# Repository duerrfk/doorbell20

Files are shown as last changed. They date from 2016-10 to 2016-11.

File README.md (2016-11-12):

# What is DoorBell20?

Door Bell 2.0 (or DoorBell20 for short) is a Bluetooth Low Energy (BLE) appliance to monitor a door bell and send notifications whenever the door bell rings. It turns a conventional door bell into a smart door bell that can be connected to the Internet of Things (IoT). Thus, DoorBell20 is the modern version of a door bell, or, as the name suggests, the door bell version 2.0 for the IoT era.

DoorBell20 consists for two major parts:

* The DoorBell20 monitoring device, which is connected in parallel to the door bell and wirelessly via BLE to a client running on a remote IoT gateway, e.g., a Raspberry Pi with Bluetooth stick.
* A DoorBell20 client running on the IoT gateway passing on notifications received via BLE to a remote cloud service. Different clients can be implemented for different IoT cloud services. So far, DoorBell20 includes a client for [If This Then That (IFTTT)](https://ifttt.com), which makes it very easy to trigger different actions when a door bell event is detected. For instance, a notification can be sent to a mobile phone or trigger an IP camera installed at the door to take pictures.

```
                  [IoT Cloud Service]
                  [  (e.g., IFTTT)  ]
                           | ^
                 Internet  | | Door Bell Event Notifications
                           |
                [      IoT Gateway      ]
                [ w/ DoorBell20 Client  ]
                [ (e.g., IFTTT Trigger) ]
                           |  ^
           BLE Connection  |  | Door Bell Event Notifications  
                           |
|-----------[DoorBell20 Monitoring Device]---------|
|                                                  |
|--------------------[Door Bell]-------------------|
|                                                  |
|                                                  |
|                                                 \   Door Bell Push Button
|                                                  \
|                                                  |
|----------------(Voltage Source)------------------|
                 (    12 VAC    )
```  

The following images show the DoorBell20 monitoring device, its connection to a door bell, and a door bell event notification displayed by the If This Then That (IFTTT) app on a mobile phone. 

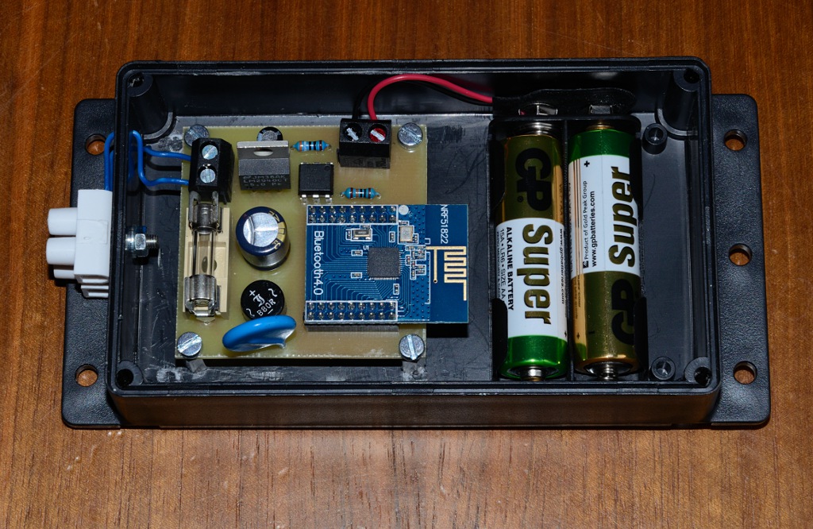
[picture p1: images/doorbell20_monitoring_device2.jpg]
DoorBell20 Monitoring Device

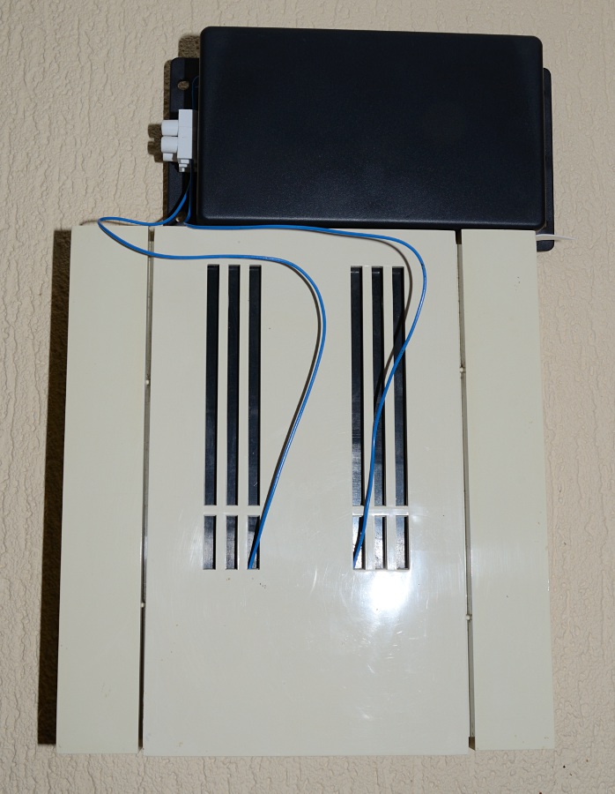
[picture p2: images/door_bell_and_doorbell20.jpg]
DoorBell20 Monitoring Device

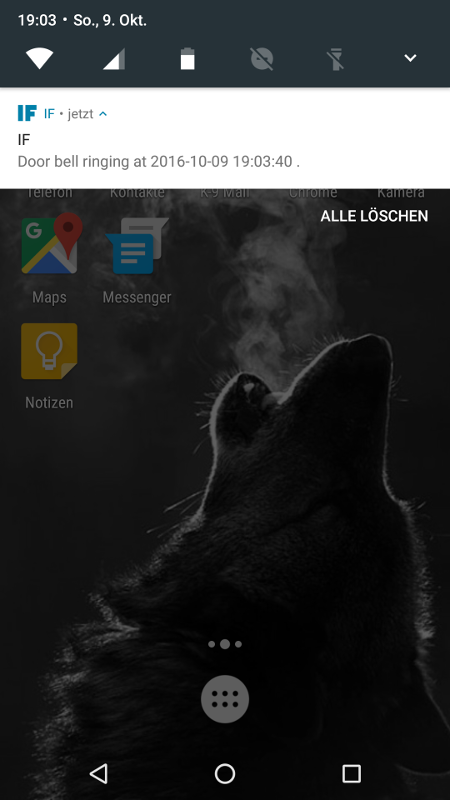
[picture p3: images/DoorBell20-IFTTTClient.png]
IFTTT Door Bell Notification


The main features of DoorBell20 are:

* Open-source software and hardware. Source code for the door bell monitoring device and IFTTT client as well as Eagle files (schematic and board layout) are provided.
* Maker-friendly: using easily available cheap standard components (nRF51822 BLE chip, standard electronic parts), easy to manufacture circuit board, and open-source software and hardware design.
* Includes a client for the popular and versatile If This Then That (IFTTT) service to facilitate the development of IoT applications integrating DoorBell20. 
* Liberal licensing of software and hardware under the Apache License 2.0 and the CERN Open Hardware License 1.0, respectively.

# DoorBell20 Monitoring Device

## Hardware

The following images show the DoorBell20 hardware and schematic.

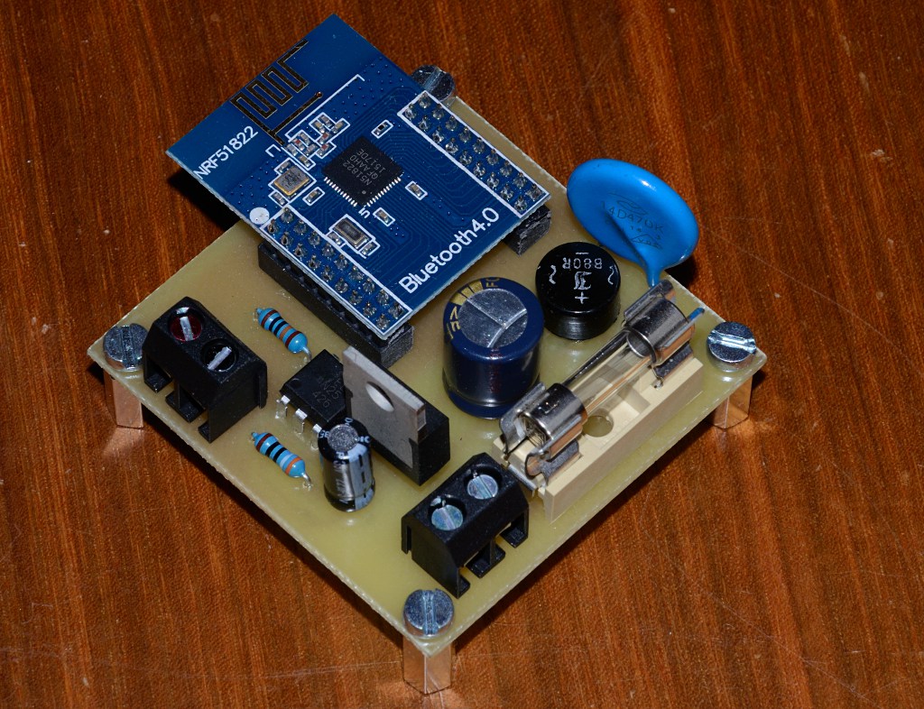
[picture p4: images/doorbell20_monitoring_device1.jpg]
DoorBell20 Monitoring Device

DoorBell20 Monitoring Device
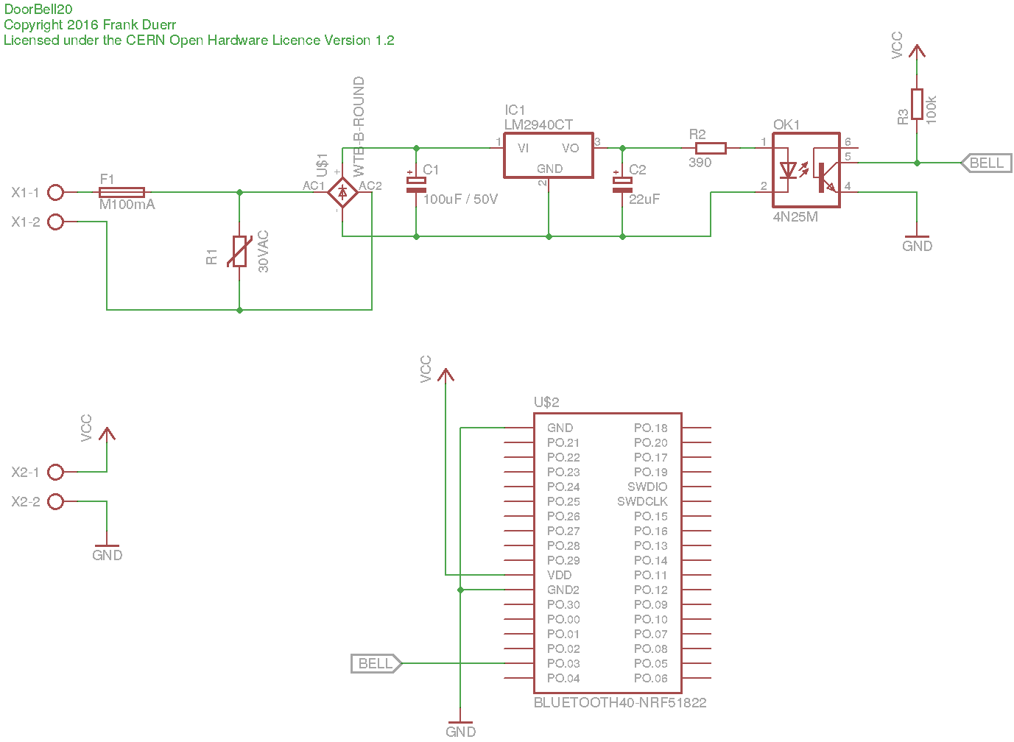
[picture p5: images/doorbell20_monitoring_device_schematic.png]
DoorBell20 Schematic


The DoorBell20 monitoring device is based on the BLE chip [nRF51822](https://www.nordicsemi.com/eng/Products/Bluetooth-low-energy/nRF51822) by Nordic Semiconductors. The nRF51822 features an ARM Cortex M0 processor implementing both, the application logic and the BLE stack (so-called softdevice). DoorBell20 uses the S110 softdevice version 8.0. See next sub-section on how to flash the softdevice and the application code. We use a so-called "Bluetooth 4.0" breakout boards with an nRF51822 (version 3, variant AA w/ 16 kB of RAM and 256 kB flash memory) and two 2x9 connectors (2 mm pitch), which you can buy over the Internet for about 6 US$ including shipping.

We isolate the 12 VAC door bell circuit from the microcontroller using an opto-isolator. A rectifier and 5 V voltage regulater is used to power the LED of the opto-isolator whenever the door bell is ringing. A GPIO pin of the nRF51822 connected to the other side of the opto-isolator is then detecting the event. In addition to the integrate protection mechanisms of the LM2940 voltage regulator (short circuit and thermal overload protection, shutdown during transients), a varistor protects from voltage transients since many door bells are inductive loads inducing voltage spikes when switched off. Since varistors age with every voltage transient, a fuse is added to protect the door bell circuit from a short circuit of the varistor.

The nRF51822 is powered by two AA batteries. No additional voltage regulator is required, which increased the energy efficiency, and the monitoring device is expected to run for years from a pair of AA batteries. Note that we did not implement a reverse polarity protection, so be careful to insert the batteries correctly.    

The circuit board layout (PCB) of the DoorBell20 monitoring device for Eagle can be found in folder ```pcb/doorbell20```. We deliberately used a simple single-sided through-hole design to help makers producing their own boards.

## Software/Firmware

The software for the DoorBell20 monitoring device can be found in directory ```nrf51/doorbell20```. 

### Prerequisites for Building the Software

No heavy-weight IDE is required to build the code. However, still a few tools are required to build and flash the code (tested with the given version numbers):

* [nRF51 SDK, version 10.0.0](http://developer.nordicsemi.com/nRF5_SDK/)
* [nRF5x Command Line Tools, version 8.2.0](https://www.nordicsemi.com/eng/Products/nRF51-DK)
* [Softdevice S110, version 8.0.0](https://www.nordicsemi.com/eng/Products/nRF51-DK)
* Flashing and debugging hardware, e.g., [Segger J-Link EDU](https://www.segger.com/j-link-edu.html) (about 50 US$, only for non-commerical use!). The nRF51 Developers Kit (DK) comes with an on-board Segger programmer, but for flashing the DoorBell20 board, you need an external programmer like the J-Link EDU. 
* [Tool chain (compiler, linker, etc.) for ARM](https://launchpad.net/gcc-arm-embedded/+download)

### Building and Flashing the Software

First, adapt the Makefile by defining the following variables:

* `NRF51_SDK`: path to the nRF51 SDK directory
* `CROSS`: path to the compiler tools
* `CFLAGS`: add `-DTARGET_BOARD_NRF51DK` if you compile for the nRF51 Development Kit (DK); if this definition is not set, you compile for the DoorBell20 board.
* `LINKER_SCRIPT`: set to `nrf51422_ac_s110.ld` for the nRF51 DK (nRF51422, variant AC) or to `nrf51822_aa_s110.ld` for the DoorBell20 board (nRF51822, variant AA).

Compiling the code:

```
$ cd nrf51
$ make
```

Flashing the softdevice:

```
$ nrfjprog --family NRF51 --program s110_nrf51_8.0.0_softdevice.hex --chiperase --verify
```

Flashing the application:

```
nrfjprog --family NRF51 --program doorbell20.hex --verify --sectorerase
```

Rebooting after flashing:

```
nrfjprog -r
```

# IFTTT DoorBell20 Client

DoorBell20 can be connected to any BLE client running on a remote machine. After receiveing a BLE notification about a door bell event, the client can then trigger local actions, and can forward the event to a remote IoT cloud service. DoorBell20 comes with a client for connecting to the popular [If This Then That (IFTTT)](https://ifttt.com/) cloud service.

You find the [nodejs](https://nodejs.org/) implementation of the IFTTT client in directory `client/ifttt`. With this client, you can use door bell alarm events as triggers for IFTTT. IFTTT offers you a broad choice of actions such as showing a notification on your smartphone when the bell rings, playing a sound on your phone, or sending a tweet to Twitter (if that makes sense to you). You could also trigger other IoT devices like an IP camera making a picture of the one standing at the door. 

The IFTTT DoorBell20 client subscribes for BLE notifications using the nodejs library [noble](https://github.com/sandeepmistry/noble). Whenever a notification for a door bell alarm is received, a web request is sent to the IFTTT maker channel triggering an event with a pre-defined name (we use the event name `door_bell_alarm` in our example). You can then define your own IFTTT recipes to decide what to do with this event like showing a notification on your smartphone through the IFTTT app. 

The following screenshot shows an IFTTT notification on an Android phone triggered by a door bell event that was delivered over the IFTTT Maker Channel.

IFTTT Door Bell Notification

## Prerequisites

The IFTTT client relies on the following software to be installed on the BLE client machine (your IoT gateway):

* nodejs (tested with nodejs version 4.6.0)
* noble
* C++ compiler with C++11 support for installing noble with npm as described below (tested with gcc/g++ 4.8.4). If you use Raspbian: gcc/g++ 4.8.4 included with Raspbian Jessie will work, but gcc/g++ 4.6.3 included with Raspbian Wheezy won't.  

Nodejs can be installed as root like this on a Raspberry Pi A/A+, B/B+, and Zero (ARMv6):

```
$ cd /usr/local
$ wget http://nodejs.org/dist/latest-v4.x/node-v4.6.0-linux-armv6l.tar.xz
$ tar axf node-v4.6.0-linux-armv6l.tar.xz
```

For other platforms, you have to replace `node-v4.6.0-linux-armv6l.tar.xz` by the corresponding file, e.g., `node-v4.6.0-linux-armv7l.tar.xz` for Raspberry Pi 2 (ARMv7) or `node-v4.6.0-linux-x64.tar.xz` for 64 bit Linux.

Make sure to add the nodejs `bin` directory to your path, so the commands `node`and `npm` can be found.

With nodejs installed, install the noble library for implementing BLE centrals:

```
$ sudo apt-get install bluetooth bluez libbluetooth-dev libudev-dev
$ cd doorbell20/client/ifttt
$ npm install noble
```

This should create the sub-directory `node_modules` in directory `doorbell20/client/ifttt`.

The first line installs Bluetooth libraries required by noble on Debian-based systems including Ubuntu and Raspbian. You might need to modify this depending on your platform, e.g., for Fedora:

```
$ sudo yum install bluez bluez-libs bluez-libs-devel
```

Please consult the [noble page](https://github.com/sandeepmistry/noble) for other platforms.

## Executing the IFTTT Client

The client can be started like this:

```
sudo node doorbell20-client-ifttt.js 'ABCDEFGHIJK1234567890' 'f3:23:0d:4c:ce:1b' 'doorbell_alarm' 'iot_failure'
```

Argument `ABCDEFGHIJK1234567890` is the key of your IFTTT Maker channel (obviously here a bogus one), which you get when you register with the Maker channel through the IFTTT web interface or app.

Argument `doorbell_alarm` is the name of the generated events. You can send many different events to your Maker channel, e.g., from your door bell, from your smoke detector (hopefully not so often), etc. The event name defines, which event has been fired.

A second event called `iot_failure` is defined that will be triggerer when the client could not connect to the DoorBell20 monitoring device over BLE to signal a permanent failure, e.g., when the battery of the monitoring device is empty. 

Argument `f3:23:0d:4c:ce:1b` is the MAC address of your DoorBell20 BLE device. You might have installed different DoorBell20 devices for different door bells, so the DoorBell20 service UUID is not enough to distinguish between different devices. The MAC address is unique for each device.

## Source Code

The source code of the IFTTT client can be found in file `doorbell20-client-ifttt.js`. It should be pretty self-explaining.

Event notifications are sent to the IFTTT channel through web requests using HTTPS. The URL defines the triggered event:

```
https://maker.ifttt.com/trigger/{event}/with/key/{key}
```

```{event}``` and ```{key}``` are replaced by the above command line arguments to define the event type and Maker channel. 

A POST request is used to send a simple JSON document with this format:

```
{ "value1" : "2016-10-09 18:37:34", "value2" : "", "value3" : "" }
```

In our application, ```value1``` defines the time when the door bell alarm event has been detected. The other two values are unused.

The client subscribes to BLE/GATT notifications of the door bell alarm characteristic of the DoorBell20 service using noble. When a BLE/GATT notification is sent, the client determines the local time of the client machine. Note that the BLE device has no wall clock time available (although is sends the local up-time of the device with every notification and allows for querying the local device time time through another characteristic). The time of the client machine is sent as timestamp of the IFTTT event notification as `value1`.

# License and Acknowledgments

The DoorBell20 software (contents of folders `nrf51` and `client`) is licensed under the Apache License, Version 2.0.

The DoorBell20 hardware documentation (contents of folder `pcb`) is licensed under the CERN Open Hardware Licence, Version 1.2

Both licenses are included in the repository in the files `LICENSE-SOFTWARE` and `LICENSE-HARDWARE`, respectively.

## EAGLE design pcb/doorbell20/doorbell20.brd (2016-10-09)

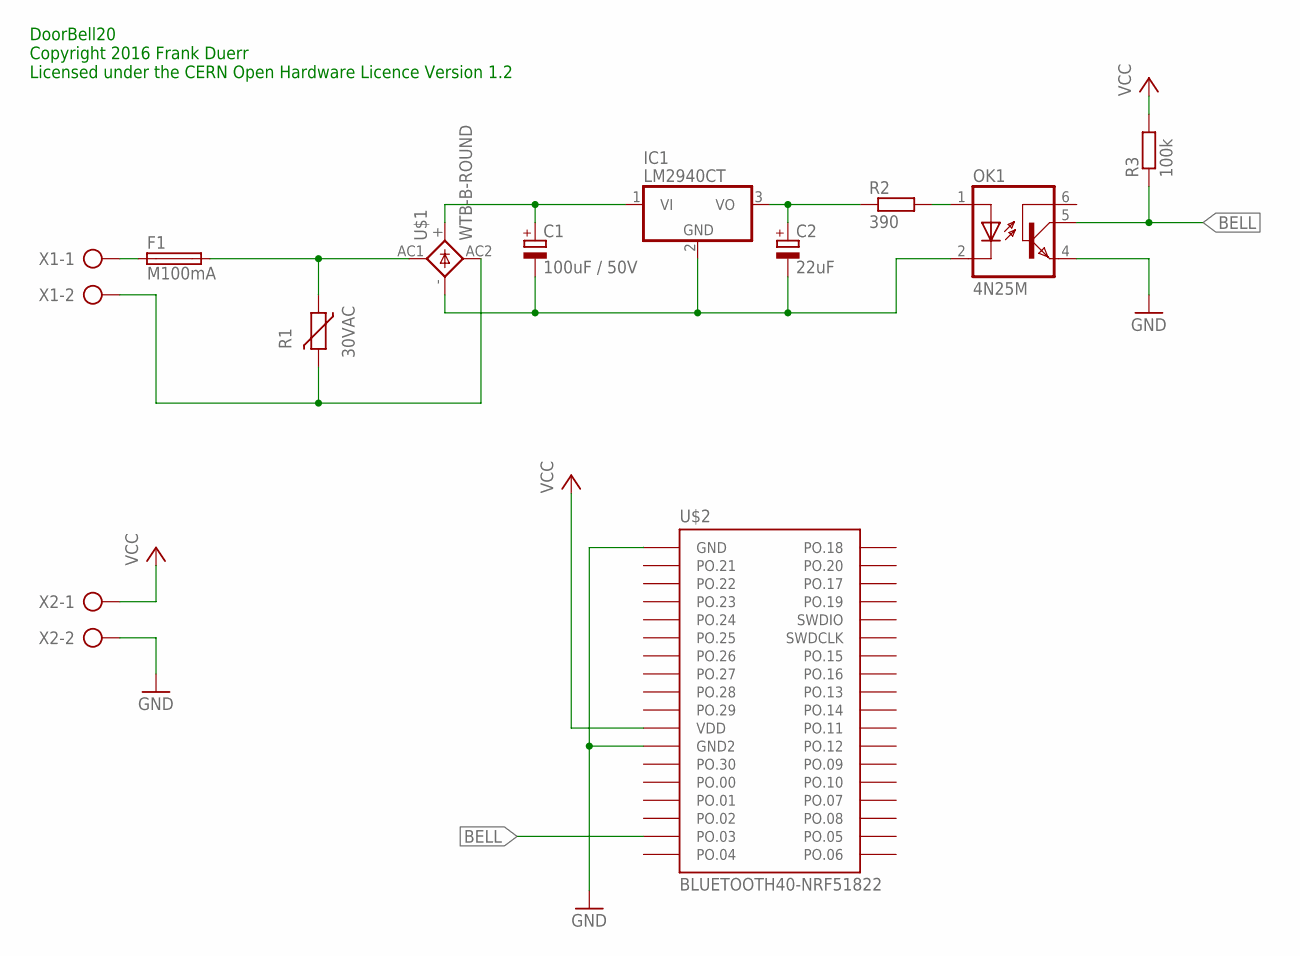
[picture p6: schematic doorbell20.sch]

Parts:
C1: 100uF / 50V; E5-10,5
C2: 22uF; E2,5-5
F1: M100mA; SH22,5A
IC1: LM2940CT; TO220V
OK1: 4N25M; DIL06
R1: 30VAC; R-7,5
R2: 390; 0207/7
R3: 100k; 0207/7
U$1: WTB-B-ROUND; WTE-B-ROUND
U$2: BLUETOOTH40-NRF51822; BLUETOOTH40-NR51822
X1, X2: AK500/2

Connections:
BELL: OK1.5 (COL), R3.1, U$2.PO.03
GND: OK1.4 (EMI), U$2.GND, U$2.GND2, X2.2
unnamed: F1.1, X1.1
unnamed: F1.2, R1.1, U$1.AC1
unnamed: C1.-, C2.-, IC1.2 (GND), OK1.2 (C), U$1.-
unnamed: C1.+, IC1.1 (VI), U$1.+
unnamed: OK1.1 (A), R2.2
unnamed: R1.2, U$1.AC2, X1.2
unnamed: C2.+, IC1.3 (VO), R2.1
VCC: R3.2, U$2.VDD, X2.1

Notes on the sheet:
DoorBell20 Copyright 2016 Frank Duerr Licensed under the CERN Open Hardware Licence Version 1.2

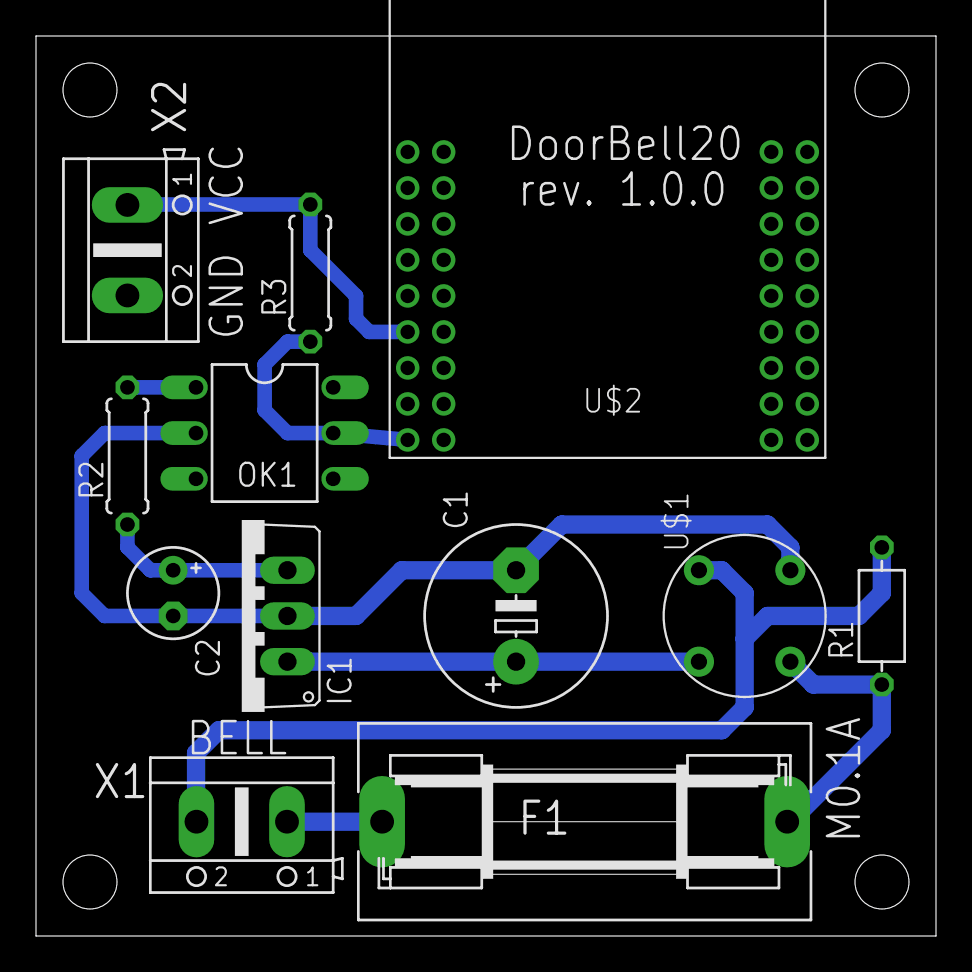
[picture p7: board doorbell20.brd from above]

Board: 2 copper layers, 50.0 x 50.0 mm, 12 parts (0 on the bottom side), 10 nets.

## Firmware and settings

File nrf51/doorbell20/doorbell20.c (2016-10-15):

/**
 * This file is part of DoorBell20.
 *
 * Copyright 2016 Frank Duerr
 *
 * Licensed under the Apache License, Version 2.0 (the "License");
 * you may not use this file except in compliance with the License.
 * You may obtain a copy of the License at
 * 
 * http://www.apache.org/licenses/LICENSE-2.0
 * 
 * Unless required by applicable law or agreed to in writing, software
 * distributed under the License is distributed on an "AS IS" BASIS,
 * WITHOUT WARRANTIES OR CONDITIONS OF ANY KIND, either express or implied.
 * See the License for the specific language governing permissions and
 * limitations under the License.
 */

#include <string.h>
#include <nrf.h>
#include <nrf_gpio.h>
#include <ble.h>
#include <softdevice_handler.h>
#include <ble_advdata.h>
#include <app_timer.h>
#include <app_button.h>
#include <ble_conn_params.h>
#include <ble_hci.h>
#include <app_util_platform.h>

#ifdef TARGET_BOARD_NRF51DK
// Pinout of development board (DK):
// * Pin 17: Button 1
// * Pin 18: Button 2 
// * Pin 21: LED 1
// * Pin 22: LED 2
#define PIN_BELL 17
#define PIN_LED 21
#else
// Pinout of DoorBell20 board:
#define PIN_BELL 3
// Actually, the DoorBell20 board has no LED.
// Pin 21 is not connected on this board, so it will also do no harm.
#define PIN_LED 21
#endif

// Max. length of door bell alarm characteristic [bytes].
#define MAX_LENGTH_DOOR_BELL_ALARM_CHAR 4

// Max. length of local time characteristic [bytes].
#define MAX_LENGTH_LOCALTIME_CHAR 4

#define DEVICE_NAME "DoorBell20"
// Minimum connection interval in 1.25 ms. Minimum allowed value: 7.5 ms.
// 80 -> 100 ms.
#define MIN_CONN_INTERVAL 80
// Maximum connection interval in 1.25 ms. Maximum allowed value: 4000 ms.
// We do not want to delay notifications too long. If the bell rings, the 
// client should get notified fast since there is someone waiting at the door
// and the client-side processing like sending a message to a mobile phone
// might take additional time.
// 160 -> 200 ms.
#define MAX_CONN_INTERVAL 160
// Number of connection intervals the device can stay silent.
// If nothing is happening, i.e., no door bell is ringing, we want to sleep
// long to save energy. With a slave latency of 5, the client gets a
// response to requests latest within 500-1000 ms assuming connection intervals 
// between 100 and 200 ms, which should be sufficiently responsive. 
#define SLAVE_LATENCY 5
// Connection supervision timeout, i.e., time until a link is considered
// lost, in 10 ms.
// 400 -> 4 s. 
#define CONN_SUP_TIMEOUT 400
// Advertisement interval in 0.625 ms; min. 20 ms, max 10.24 s.
// 1600 -> 1000 ms.
#define ADV_INTERVAL 1600
// How long to advertise in seconds (0 = forever)
#define ADV_TIMEOUT 0

// Time after making a connection when to start negotiation of connection 
// timing parameters [ms].
// -> 5 s
#define FIRST_CONN_PARAMS_UPDATE_DELAY 5000
// Time when to re-negotiate connection timing parameters [ms].
#define NEXT_CONN_PARAMS_UPDATE_DELAY 30000
// Maximum number of attempts while negotiating connecting timing parameters. 
#define MAX_CONN_PARAMS_UPDATE_COUNT 3

// Prescaler of RTC1 (low-frequency clock at 32.768 kHz), which is used by the 
// app timer (RTC0 is used by the softdevice, and, therefore, cannot be used by 
// the application). 
#define APP_TIMER_PRESCALER 0
#define APP_TIMER_QUEUE_SIZE 4

// Delay for debouncing door bell signals [ms].
#define DEBOUNCING_DELAY APP_TIMER_TICKS(50, APP_TIMER_PRESCALER)

// Delay for not accepting another door bell event. This delay defines
// how long two door bell events must be separated in time to be considered
// two individual events. Note that some users might ring several times in
// a short period of time. In such cases, we only want to send one event.
// -> 1 min
#define ALARM_INHIBIT_DELAY APP_TIMER_TICKS(60000, APP_TIMER_PRESCALER)

// The clock for updating the local time ticks every 
// LOCALTIME_CLOCK_INTERVAL_SEC seconds. Thus, we need to add this amount of 
// seconds every time the clock ticks.
#define LOCALTIME_CLOCK_INTERVAL_SEC 15
#define LOCALTIME_CLOCK_INTERVAL APP_TIMER_TICKS(\
(1000*LOCALTIME_CLOCK_INTERVAL_SEC), APP_TIMER_PRESCALER)

// Service and charateristic UUIDs in Little Endian format.
// The 16 bit values will become byte 12 and 13 of the 128 bit UUID:
// 0x451eXXXX-dd1c-4f20-a42e-ff91a53d2992
// 0x0a9dXXXX-5ff4-4c58-8a53627de7cf1faf
#define UUID_BASE {0x92, 0x29, 0x3d, 0xa5, 0x91, 0xff, 0x2e, 0xa4, \
	           0x20, 0x4f, 0x1c, 0xdd, 0x00, 0x00, 0x1e, 0x45}
#define UUID_SERVICE 0x0001
#define UUID_CHARACTERISTIC_DOOR_BELL_ALARM 0x0002
#define UUID_CHARACTERISTIC_LOCALTIME 0x0003

APP_TIMER_DEF(alarm_inhibit_timer);
APP_TIMER_DEF(localtime_timer);

uint8_t uuid_type;
uint16_t service_handle;
ble_gatts_char_handles_t char_handle_door_bell_alarm;
ble_gatts_char_handles_t char_handle_localtime;
uint16_t conn_handle = BLE_CONN_HANDLE_INVALID; 

// This variable signals, whether a client has subscribed to receive
// door bell alarm events.
volatile bool is_client_subscribed = false;

// This variable shows whether door bell events are blocked at the moment.
volatile bool is_alarm_inhibited = false;

// Local time of last door bell alarm.
// The variable is word-aligned to use single atomic LDR and STR operations to 
// load and store the variable.
uint32_t door_bell_alarm_time __attribute__ ((aligned (4))) = 0;

// Local time in seconds. 
// Local time has no relation to wall-clock time.
// Local time is updated with the interval defined by 
// LOCALTIME_CLOCK_INTERVAL_SEC. 
// The variable is word-aligned to use single atomic LDR and STR operations to 
// load and store the variable.
volatile uint32_t localtime __attribute__ ((aligned (4))) = 1;

volatile bool is_localtime_updated = false;
volatile bool is_door_bell_alarm = false;

static void led_off()
{
     // LED is active low -> set to turn off.
     nrf_gpio_pin_set(PIN_LED);
}

static void led_on()
{
     // LED is active low -> clear to turn on.
     nrf_gpio_pin_clear(PIN_LED);
}

static void led_init()
{
     nrf_gpio_cfg_output(PIN_LED);
     led_off();
}

/**
 * We follow the "let it crash" paradigm known from Erlang. If something
 * unexpected happens (in particular, an SDK function not returning
 * NRF_SUCCESS), we reboot the system. So "die" actually means, die and
 * be reborn ("self-healing"). Besides that, we of course try to avoid 
 * situations where things might fail (defensive programming). However, 
 * in very unlikely failure situations, we opt for crashing and rebooting 
 * rather than overloading code (and precious code memory) with failure 
 * handling routines.
 */
static void die()
{
     __disable_irq();
 
     // In a development system, we loop forever.
     // Remove the endless loop in a productive system to auto-reset.
     //while (1);
     
     // In a productive system, we automatically reset the system on errors.
     sd_nvic_SystemReset();
}

static void start_advertising()
{
    uint32_t err_code;
    ble_gap_adv_params_t adv_params;

    memset(&adv_params, 0, sizeof(adv_params));
    adv_params.type = BLE_GAP_ADV_TYPE_ADV_IND;
    adv_params.p_peer_addr = NULL;
    adv_params.fp = BLE_GAP_ADV_FP_ANY;
    adv_params.interval = ADV_INTERVAL;
    adv_params.timeout = ADV_TIMEOUT;

    err_code = sd_ble_gap_adv_start(&adv_params);
    if (err_code != NRF_SUCCESS)
	 die();
}

static void cccd_door_bell_alarm_write_evt(ble_gatts_evt_write_t *evt_write)
{
     // A subscription is made by the client by writing the characteristic's
     // CCCD (Client Characteristic Configuration Descriptor). A value of 
     // 0x0001 signals a subscription to notifications;
     // 0x0002 signals a subscription to indications. See:
     // See https://www.bluetooth.com/specifications/gatt/
     // viewer?attributeXmlFile=org.bluetooth.descriptor.gatt.
     // client_characteristic_configuration.xml
     if (evt_write->handle == char_handle_door_bell_alarm.cccd_handle) {
	  if (evt_write->data[0] == 0x01 && evt_write->data[1] == 0x00) {
	       // Client subscribed to door bell alarm events.
	       is_client_subscribed = true;
	  } else if (evt_write->data[0] == 0x00 && evt_write->data[1] == 0x00) {
	       // Client unsubscribed from door bell alarm events.
	       is_client_subscribed = false;
	  }
     }
}

static void on_sys_evt(uint32_t sys_evt)
{
     // No need to handle any system events.
}

static void sys_evt_dispatch(uint32_t sys_evt)
{
    on_sys_evt(sys_evt);
}

static void ble_evt_handler(ble_evt_t *ble_evt)
{
     ble_gatts_evt_write_t *evt_write;

     switch (ble_evt->header.evt_id) {
     case BLE_GAP_EVT_CONNECTED:
	  conn_handle = ble_evt->evt.gap_evt.conn_handle;
	  // If we sometimes use bonding, note that bonded devices might 
	  // already have subscribed when they connect. Subscriptions 
	  // are stored for bonded devices.
	  is_client_subscribed = false;
	  break;
     case BLE_GAP_EVT_DISCONNECTED:
	  conn_handle = BLE_CONN_HANDLE_INVALID;
	  start_advertising();
	  break;
     case BLE_GAP_EVT_SEC_PARAMS_REQUEST:
	  // Pairing not supported.
	  sd_ble_gap_sec_params_reply(conn_handle, 
				      BLE_GAP_SEC_STATUS_PAIRING_NOT_SUPP,
				      NULL, NULL);
	  break;
     case BLE_GATTS_EVT_WRITE:
	  evt_write = &ble_evt->evt.gatts_evt.params.write;
	  cccd_door_bell_alarm_write_evt(evt_write);
	  break;
     case BLE_GATTS_EVT_HVC:
	  // Indication has been acknowledged by the client.
	  // Not used. We just send notifications.
	  break;
     case BLE_GATTS_EVT_SYS_ATTR_MISSING:
	  // No system attributes have been stored.
	  sd_ble_gatts_sys_attr_set(conn_handle, NULL, 0, 0);
	  break;
     case BLE_GAP_EVT_TIMEOUT:
	  // TODO: Should we do something?
	  break;
    }
}

static void ble_stack_init()
{
     // The softdevice uses RTC0 (32 kHz real-time clock) for timing.
     // We use an external crystal with 20 ppm accuracy.
     SOFTDEVICE_HANDLER_INIT(NRF_CLOCK_LFCLKSRC_XTAL_20_PPM, false);

     // Enable BLE stack. 
     ble_enable_params_t ble_enable_params;
     memset(&ble_enable_params, 0, sizeof(ble_enable_params));
     if (sd_ble_enable(&ble_enable_params) != NRF_SUCCESS)
	  die();
     
     // Set Bluetooth address of device.
     ble_gap_addr_t addr;
     if (sd_ble_gap_address_get(&addr) != NRF_SUCCESS)
	  die();
     if (sd_ble_gap_address_set(BLE_GAP_ADDR_CYCLE_MODE_NONE, &addr) !=
	 NRF_SUCCESS)
	  die();
     
     // Subscribe for BLE events.
     if (softdevice_ble_evt_handler_set(ble_evt_handler) != NRF_SUCCESS)
	  die();
     
     // Subscribe for system events.
     // Actually, so far, we do not need to handle any system events.
     // But maybe in the future, for instance, when we store some events
     // persistently in flash or similar.
     if (softdevice_sys_evt_handler_set(sys_evt_dispatch) !=
	 NRF_SUCCESS)
	  die();
}

static void gap_init()
{
     ble_gap_conn_params_t gap_conn_params;
     ble_gap_conn_sec_mode_t sec_mode;

     // Open link, no encryption required on BLE layer.
     BLE_GAP_CONN_SEC_MODE_SET_OPEN(&sec_mode);
     
     // Set device name.
     if (sd_ble_gap_device_name_set(&sec_mode,
				    (const uint8_t *) DEVICE_NAME,
				    strlen(DEVICE_NAME)) != NRF_SUCCESS)
	  die();
     
     // Set connection parameters.
     memset(&gap_conn_params, 0, sizeof(gap_conn_params));
     gap_conn_params.min_conn_interval = MIN_CONN_INTERVAL;
     gap_conn_params.max_conn_interval = MAX_CONN_INTERVAL;
     gap_conn_params.slave_latency = SLAVE_LATENCY;
     gap_conn_params.conn_sup_timeout = CONN_SUP_TIMEOUT;     
     if (sd_ble_gap_ppcp_set(&gap_conn_params) != NRF_SUCCESS)
	  die();
}

static void set_localtime_char()
{
     // Make a copy of localtime to avoid race conditions of
     // concurrent write operations to variable localtime.
     // 32 bit load operations are atomic on ARM Cortex M0, so we do not
     // need to protect this assignment by disabling interrupts.
     uint32_t t = localtime;

     ble_gatts_value_t value;
     value.len = sizeof(t);
     value.offset = 0;
     value.p_value = (uint8_t *) &t;

     if (sd_ble_gatts_value_set(conn_handle, 
				char_handle_localtime.value_handle,
				&value) != NRF_SUCCESS)
	  die();
}

static void set_door_bell_alarm_char()
{
     // Make a copy of door_bell_alarm_time to avoid race conditions of
     // concurrent write operations to variable door_bell_alarm_time.
     // 32 bit load operations are atomic on ARM Cortex M0, so we do not
     // need to protect this assignment by disabling interrupts.
     uint32_t t = door_bell_alarm_time;

     ble_gatts_value_t value;
     value.len = sizeof(t);
     value.offset = 0;
     value.p_value = (uint8_t *) &t;

     if (sd_ble_gatts_value_set(conn_handle, 
				char_handle_door_bell_alarm.value_handle,
				&value) != NRF_SUCCESS)
	  die();
}

static void add_characteristic_door_bell_alarm(uint16_t service_handle)
{
     // Characteristic UUID.
     ble_uuid_t ble_uuid;
     ble_uuid.type = uuid_type;
     ble_uuid.uuid = UUID_CHARACTERISTIC_DOOR_BELL_ALARM;

     // Define characteristic presentation format.
     // The door bell alarm is a single unsigned 32 bit integer representing
     // a timestamp when the event happened.
     ble_gatts_char_pf_t char_presentation_format;
     memset(&char_presentation_format, 0, sizeof(char_presentation_format));
     char_presentation_format.format = BLE_GATT_CPF_FORMAT_UINT32;
     char_presentation_format.exponent = 0;
     char_presentation_format.unit = 0x2703; // seconds

     // Define CCCD attributes. 
     // CCCD (Client Characteristic Configuration Descriptor) is used by the
     // client to enable notifications or indications by writing a flag to the
     // CCCD attribute.
     ble_gatts_attr_md_t cccd_meta_data;
     memset(&cccd_meta_data, 0, sizeof(cccd_meta_data));
     // CCCD must be readable and writeable. 
     BLE_GAP_CONN_SEC_MODE_SET_OPEN(&cccd_meta_data.read_perm);
     BLE_GAP_CONN_SEC_MODE_SET_OPEN(&cccd_meta_data.write_perm);
     cccd_meta_data.vloc = BLE_GATTS_VLOC_STACK;

     // Define characteristic meta data.
     // The door bell alarm is readable and can send notifications.
     ble_gatts_char_md_t char_meta_data;
     memset(&char_meta_data, 0, sizeof(char_meta_data));
     char_meta_data.char_props.read = 1;
     char_meta_data.char_props.write = 0;
     char_meta_data.char_props.notify = 1;
     char_meta_data.char_props.indicate = 0;
     char_meta_data.p_char_user_desc = NULL;
     char_meta_data.p_char_pf = &char_presentation_format;
     char_meta_data.p_user_desc_md = NULL;
     // CCCD (Client Characteristic Configuration Descriptor) needs to be 
     // set for characteristics allowing for notifications and indications.
     char_meta_data.p_cccd_md = &cccd_meta_data;
     char_meta_data.p_sccd_md = NULL;

     // Define attribute meta data. 
     ble_gatts_attr_md_t char_attr_meta_data;
     memset(&char_attr_meta_data, 0, sizeof(char_attr_meta_data));
     // No security needed.
     BLE_GAP_CONN_SEC_MODE_SET_OPEN(&char_attr_meta_data.read_perm);
     BLE_GAP_CONN_SEC_MODE_SET_NO_ACCESS(&char_attr_meta_data.write_perm);
     // value location
     char_attr_meta_data.vloc = BLE_GATTS_VLOC_STACK;
     // always request read authorization from application 
     char_attr_meta_data.rd_auth = 0;
     // always request write authorization from application
     char_attr_meta_data.wr_auth = 0;
     // variable length attribute
     char_attr_meta_data.vlen = 0;

     // Define characteristic attributes. 
     // Door bell alarm is a fixed length 32 bit data structure.
     ble_gatts_attr_t char_attributes;
     memset(&char_attributes, 0, sizeof(char_attributes));
     char_attributes.p_uuid = &ble_uuid;
     char_attributes.p_attr_md = &char_attr_meta_data;
     char_attributes.init_len = sizeof(door_bell_alarm_time);
     char_attributes.init_offs = 0;
     char_attributes.max_len = MAX_LENGTH_DOOR_BELL_ALARM_CHAR;
     // For attributes managed by the application (BLE_GATTS_VLOC_USER)
     // rather than the BLE stack, set a pointer to the memory location here.
     char_attributes.p_value = (uint8_t *) &door_bell_alarm_time;

     // Add characteristic to service.
     if (sd_ble_gatts_characteristic_add(service_handle,
					 &char_meta_data,
					 &char_attributes,
					 &char_handle_door_bell_alarm) 
	 != NRF_SUCCESS)
	  die();
}

static void add_characteristic_localtime(uint16_t service_handle)
{
     // Characteristic UUID.
     ble_uuid_t ble_uuid;
     ble_uuid.type = uuid_type;
     ble_uuid.uuid = UUID_CHARACTERISTIC_LOCALTIME;

     // Define characteristic presentation format.
     // The localtime characteristic is a single unsigned 32 bit integer 
     // representing a timestamp in seconds.
     ble_gatts_char_pf_t char_presentation_format;
     memset(&char_presentation_format, 0, sizeof(char_presentation_format));
     char_presentation_format.format = BLE_GATT_CPF_FORMAT_UINT32;
     char_presentation_format.exponent = 0;
     char_presentation_format.unit = 0x2703; // seconds

     // Define characteristic meta data.
     // Localtime is readable.
     ble_gatts_char_md_t char_meta_data;
     memset(&char_meta_data, 0, sizeof(char_meta_data));
     char_meta_data.char_props.read = 1;
     char_meta_data.char_props.write = 0;
     char_meta_data.char_props.notify = 0;
     char_meta_data.char_props.indicate = 0;
     char_meta_data.p_char_user_desc = NULL;
     char_meta_data.p_char_pf = &char_presentation_format;
     char_meta_data.p_user_desc_md = NULL;
     // CCCD (Client Characteristic Configuration Descriptor) needs to be 
     // set for characteristics allowing for notifications and indications.
     char_meta_data.p_cccd_md = NULL;
     char_meta_data.p_sccd_md = NULL;

     // Define attribute meta data. 
     ble_gatts_attr_md_t char_attr_meta_data;
     memset(&char_attr_meta_data, 0, sizeof(char_attr_meta_data));
     // No security needed.
     BLE_GAP_CONN_SEC_MODE_SET_OPEN(&char_attr_meta_data.read_perm);
     BLE_GAP_CONN_SEC_MODE_SET_NO_ACCESS(&char_attr_meta_data.write_perm);
     // value location
     char_attr_meta_data.vloc = BLE_GATTS_VLOC_STACK;
     // always request read authorization from application 
     char_attr_meta_data.rd_auth = 0;
     // always request write authorization from application
     char_attr_meta_data.wr_auth = 0;
     // variable length attribute
     char_attr_meta_data.vlen = 0;

     // Define characteristic attributes. 
     ble_gatts_attr_t char_attributes;
     memset(&char_attributes, 0, sizeof(char_attributes));
     char_attributes.p_uuid = &ble_uuid;
     char_attributes.p_attr_md = &char_attr_meta_data;
     char_attributes.init_len = sizeof(localtime);
     char_attributes.init_offs = 0;
     char_attributes.max_len = MAX_LENGTH_LOCALTIME_CHAR;
     // For attributes managed by the application (BLE_GATTS_VLOC_USER)
     // rather than the BLE stack, set a pointer to the memory location here.
     char_attributes.p_value = (uint8_t *) &localtime;

     // Add characteristic to service.
     if (sd_ble_gatts_characteristic_add(service_handle,
					 &char_meta_data,
					 &char_attributes,
					 &char_handle_localtime) 
	 != NRF_SUCCESS)
	  die();
}

static void service_init()
{
     uint32_t err_code;
     
     // Add base UUID to list of base UUIDs.
     // The uuid_type field filled by this function call can be used later to
     // refer to this base UUID.
     ble_uuid128_t base_uuid = {UUID_BASE};
     err_code = sd_ble_uuid_vs_add(&base_uuid, &uuid_type);
     if (err_code != NRF_SUCCESS)
	  die();

     // Build 128 bit service UUID by referring to base UUID using uuid_type
     // and specifying the two bytes that will replace byte 12 and 13 of the
     // base UUID. 
     ble_uuid_t ble_uuid;
     ble_uuid.type = uuid_type;
     ble_uuid.uuid = UUID_SERVICE;
     
     err_code = sd_ble_gatts_service_add(BLE_GATTS_SRVC_TYPE_PRIMARY, 
					 &ble_uuid, &service_handle);
     if (err_code != NRF_SUCCESS)
	  die();
     
     // Add characteristics to service.
     add_characteristic_door_bell_alarm(service_handle);
     add_characteristic_localtime(service_handle);
}

static void conn_params_error_handler(uint32_t nrf_error)
{
     die();
}
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
int main(void)
{
     led_init();
	       
     timers_init();
     buttons_init();
     ble_stack_init();
     gap_init();
     service_init();
     advertising_init();
     conn_params_init();

     start_localtime_timer();
     start_advertising();
     start_button_event_detection();

     while (1) {
	  // The following function puts the processor into sleep mode
	  // and waits for interrupts to wake up. Wakeup events include
	  // events from the softdevice, which are processed in the BLE event 
	  // loop, or other events like interrupts from application timers and
	  // pressed buttons.
	  sd_app_evt_wait();

	  if (is_localtime_updated) {
	       // Update the localtime characteristic value to reflect current
	       // time.
	       set_localtime_char();
	       is_localtime_updated = false;
	  }
	  
	  if (is_door_bell_alarm) {
	       if (!is_alarm_inhibited) {
		    // This is the only place where where variable 
		    // door_bell_alarm_time is written. So we do not have to 
		    // protect it against concurrent write operations. 
		    // Moreover, the 32 bit load operation for reading 
		    // variable localtime is atomic on ARM Cortex M0. Thus, we 
		    // do not need to protect this load operation against 
		    // concurrent updates by disabling interrupts.
		    door_bell_alarm_time = localtime;
		    if (is_client_subscribed) {
			 notify_door_bell_alarm();	 
		    } else {
			 set_door_bell_alarm_char();
		    }
		    is_alarm_inhibited = true;
		    start_alarm_inhibit_timer();
	       }
	       is_door_bell_alarm = false;
	  }
     }
}

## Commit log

2016-10-09 Initial check-in
    [doorbell20.brd, doorbell20.sch]
2016-10-15 Added disconnection timeout to IFTTT client. Rebooting BLE device in case of errors.
    [doorbell20.c]
2016-11-12 Added screenshot and schematic image.
